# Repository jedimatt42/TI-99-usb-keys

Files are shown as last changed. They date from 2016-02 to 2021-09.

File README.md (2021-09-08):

# TI-99-usb-keys
Teensy 3.1 sketch to translate usb keyboard to TI-99/4a 15 pin interface.

This project interfaces a Teensy 3.1 and a Circuits@Home USB Host shield, to take input from a USB keyboard, and simulate the matrix keyboard built into the TI. 

The USB keyboard can be used with the TI keyboard still in place. The user can switch between them at will.

[Project Website](https://www.jedimatt42.com/ti99usbkeys.html)

## Design files

TIUSBKeys.rrb - PCBoard layout from Robot Room Copper Connection Studio Edition v3.0

gerber - folder containing necessary gerber images and drill files for printing pcboard

TIUSBKeys.sch - PCBExpress schematic source file

schematic.pdf - schematic exported to PDF

TI99USBKeys - folder containing arduino project files for Teensy 3.x

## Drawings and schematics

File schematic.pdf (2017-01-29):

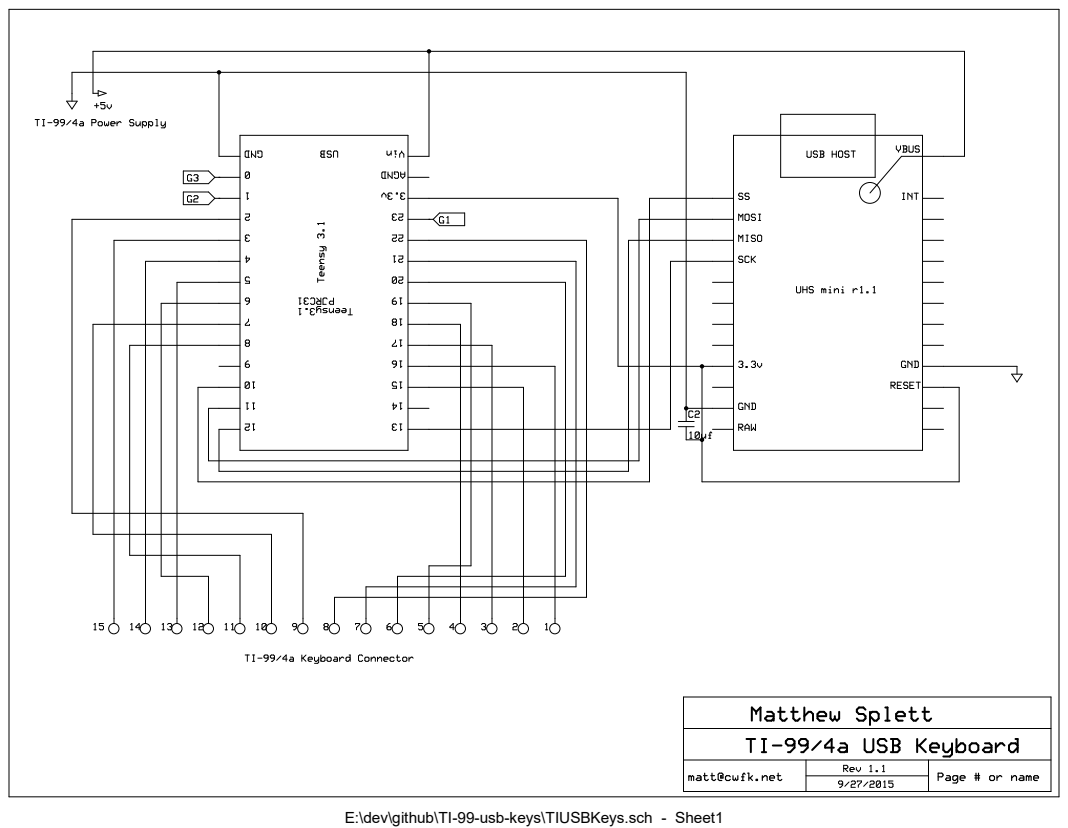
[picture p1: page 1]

E:\dev\github\TI-99-usb-keys\TIUSBKeys.sch - Sheet1

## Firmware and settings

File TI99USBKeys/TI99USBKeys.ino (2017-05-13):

#include <hidboot.h>
#include <usbhub.h>

// Satisfy the IDE, which needs to see the include statment in the ino too.
#ifdef dobogusinclude
#include <spi4teensy3.h>
#include <SPI.h>
#endif

// Reboot support
#define CPU_RESTART_ADDR (uint32_t *)0xE000ED0C
#define CPU_RESTART_VAL 0x5FA0004
#define CPU_RESTART (*CPU_RESTART_ADDR = CPU_RESTART_VAL);

#define NUMLOCK_STARTUP true
#define CAPSLOCK_STARTUP true
#define SCROLLLOCK_STARTUP false

#include "TiPins.h"

#include "TiVirtualState.h"

#include "TiScan.h"

#include "TiKbdRptParser.h"

USB     Usb;
USBHub     Hub(&Usb);
HIDBoot<HID_PROTOCOL_KEYBOARD>    HidKeyboard(&Usb);

TiKbdRptParser Prs;

long lastGoodState;
long firstBoot;

void setup()
{
  firstBoot = lastGoodState = millis();
  
  initData();

  // Wait for keyboard to be up
  while (Usb.Init() == -1)
    delay( 20 );

  HidKeyboard.SetReportParser(0, (HIDReportParser*)&Prs);
}

void gpioSetup()
{
  initPinModes();
  setColumnInterrupts();
}

void loop()
{
  // Read USB input which updates the state of the in-memory keyboard matrix.
  Usb.Task();

  long loopMillis = millis();
  uint8_t state = Usb.getUsbTaskState();
  
  if (state != USB_STATE_RUNNING) {
    if ((loopMillis - lastGoodState) > 5000) {
      CPU_RESTART;
    }
  } else {
    lastGoodState = loopMillis;
    if (firstBoot != 0) {
      // Set numlock and capslock on, leave scroll lock off.
      Prs.setKeyLocks(&HidKeyboard, NUMLOCK_STARTUP, CAPSLOCK_STARTUP, SCROLLLOCK_STARTUP);
      firstBoot = 0; 
      gpioSetup();
    }
  }
  if ((loopMillis - lastInterrupted) > 200) {
    onTiColumnChange();
  }
}

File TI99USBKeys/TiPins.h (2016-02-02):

#ifndef _TI_PINS_H
#define _TI_PINS_H

// teensy 3.1 pin aliases for TI keyboard connector. 
//   and info describing the meaning. 
//   _c? is a column input pin from the TI
//   _r? is a row output pin for the TI
int ti_c3 = 3; // key_cable_pin_15  (M J U 7 4 F R V)
int ti_c2 = 4; // key_cable_pin_14  (, K I 8 3 D E C)
int ti_c1 = 5; // key_cable_pin_13  (. L O 9 2 S W X)
int ti_c0 = 6; // key_cable_pin_12  (= space enter fctn shift ctrl)
int ti_r7 = 8; // key_cable_pin_11 (X C V B Z)
int ti_r6 = 7; // key_cable_pin_10 (ctrl W E R T Q)
int ti_c4 = 2; // key_cable_pin_9   (N H Y 6 5 G T B)
int ti_c5 = 22; // key_cable_pin_8   (/ ; P 0 1 A Q Z)
int ti_r4 = 21; // key_cable_pin_7  (fctn 2 3 4 5 1 alpha_lock)
int ti_c6 = 20; // key_cable_pin_6   (alpha_lock)
int ti_r0 = 19; // key_cable_pin_5  (= . , M N /)
int ti_r1 = 18; // key_cable_pin_4  (space L K J H ;)
int ti_r5 = 17; // key_cable_pin_3  (shift S D F G A)
int ti_r3 = 15; // key_cable_pin_2  (9 8 7 6 0)
int ti_r2 = 16; // key_cable_pin_1  (enter O I U Y P)

int ti_g3 = 0;
int ti_g2 = 1;
int ti_g1 = 23;

//-------------------------------------
// Initialize the TI interfacing pins.


void initInputs() 
{
  int inputMode = INPUT_PULLUP;
  pinMode(ti_c0, inputMode);
  pinMode(ti_c1, inputMode);
  pinMode(ti_c2, inputMode);
  pinMode(ti_c3, inputMode);
  pinMode(ti_c4, inputMode);
  pinMode(ti_c5, inputMode);
  pinMode(ti_c6, inputMode);
}

void initOutputs()
{
  // this mode seems to work well with letting the TI builtin keyboard still function.
  int outputMode = OUTPUT_OPENDRAIN; 
  pinMode(ti_r0, outputMode);
  pinMode(ti_r1, outputMode);
  pinMode(ti_r2, outputMode);
  pinMode(ti_r3, outputMode);
  pinMode(ti_r4, outputMode);
  pinMode(ti_r5, outputMode);
  pinMode(ti_r6, outputMode);
  pinMode(ti_r7, outputMode);
  digitalWrite(ti_r0,HIGH);
  digitalWrite(ti_r1,HIGH);
  digitalWrite(ti_r2,HIGH);
  digitalWrite(ti_r3,HIGH);
  digitalWrite(ti_r4,HIGH);
  digitalWrite(ti_r5,HIGH);
  digitalWrite(ti_r6,HIGH);
  digitalWrite(ti_r7,HIGH);

  pinMode(ti_g1, INPUT_PULLUP);
  pinMode(ti_g2, INPUT_PULLUP);
  pinMode(ti_g3, INPUT_PULLUP);
  digitalWrite(ti_g1,HIGH);
  digitalWrite(ti_g2,HIGH);
  digitalWrite(ti_g3,HIGH);
}

void initPinModes() 
{
  initInputs();
  initOutputs();
}

#endif

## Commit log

2015-09-10 Initial commit.
    Use mode to pins source for teensy to use opendrain mode of output pins
    for interfacing with pull up inputs on TI keyboard 'controller'
2015-09-13 remove the wait-for-serial loop so it will run off TI power supply.
    Also, added another sketch for experimenting with simply reading TI cru
    scans.
2015-09-13 Support strange directory requirements for Arduino IDE
2015-09-13 best guess at pinmodes for TI keyboard cable.
2015-09-16 basic buttons mapped, get lots of 'key-bounce' like behavior
    and some ghost keys from other columns. :(
2015-09-18 Fix mapping of single and double quote.
    Fix ti row updates to be faster. Seems fine. Now the key repeating has
    stopped.
    Added a naive version of alpha-lock. But it doesn't work well.
    I'm seeing some shift-lock like behavior that may be the result of the
    alpha-lock code.
    [TI99USBKeys.ino]
2015-09-20 first draft of schematic and pcboard.
    [TIUSBKeys.sch]
2015-09-20 capture some code that can soft reset the teensy. and document the keymap.
    [keymap.xlsx]
2015-09-20 Add ctrl-alt-delete to reboot adapter cpu. Fix F=.
    [TI99USBKeys.ino]
2015-09-20 Added data initialization explicit to setup.
    In case data segments are not otherwise initialized on reboot.
    [TI99USBKeys.ino]
2015-09-21 Forgot to undu an experiment. Put OPENDRAIN back.
    With my output pins in OPENDRAIN mode, they are either HIGH - not
    connected, or LOW - connected to ground. This doesn't interfere
    with the legacy keyboard at all... so they can both be present.
    [TI99USBKeys.ino]
2015-09-22 add scroll-lock and num-lock functions.
    Numlock is backwards for some reason. ( cause my code is bad.. and I
    haven't looked at it yet ) but the scroll lock works.
    I've also debugged the shift lock bug at the hardware level. And to my
    relief, it is a software problem :)
    [TI99USBKeys.ino]
2015-09-23 Hot plugging works.
    Waits on startup for device, and if device is disconnected / or any error,
    reboots after 5 seconds, which causes it to go back to waiting for device
    on startup.
    [TI99USBKeys.ino]
2015-09-26 This breakup now compiles and runs as before on the device.
2015-09-27 Finally fixed key lock states on start up.
    CapsLock and NumLock on by default.
    [TI99USBKeys.ino, TiKbdRptParser.h]
2015-09-29 A different layout approach.
    [TIUSBKeys.sch]
2015-09-30 Refine pcb layout, and adjust pin assignments to suite layout.
2015-10-03 Redo of pcboard layout to make it smaller.
    This will require updating the pin assignments.
    In a followup.
2015-10-04 even smaller so connectors protrude more.
2015-10-04 Update pin assignments to match board layout.
2015-10-04 Update pinouts on schematic.
    [TIUSBKeys.sch]
2015-10-09 Try using change interrupt detection.
    This should enable holding modifiers, and releasing keys more effectively.
    And if I'm lucky, it may get rid of the latency that causes '.', to produce
    strings of '.', and '/'...
2015-10-10 fix issues with repeating . and /, overlapping interrupts.
    Removed a few key specific hacks.
    So Fctn= is broken again. It won't release.
    [TI99USBKeys.ino, TiKbdRptParser.h]
2015-10-10 Fix alpha lock.
    It can coincide with other keys since it has a activation pin on the 9901,
    instead of the decoded set that go through the octal decoder.
2015-10-10 This fixes issues using the zero key in pinball II.
    I expected this to also replace my previous workaround for Fctn=, but it
    doesn't. It is like there is a bad interaction with the 9901 while it is
    resetting.
    [TI99USBKeys.ino]
2015-10-12 Fix fctn= to work with my normal failsafe relese mechanism.
    work arounds didn't help because they all made the assumption that the
    virtualstate was being cleared properly. It wasn't until I put the TI
    into a boot loop, that I realized the state must be stuck, and there it
    was, forcing on, instead of toggling like it should.
    [TI99USBKeys.ino, TiKbdRptParser.h]
2015-10-13 fix backspace to ignore scrolllock state, always be backspace.
    [TiKbdRptParser.h]
2015-12-13 update to include required 10uf cap over +3.3v input to USB Host mini.
    [TIUSBKeys.sch]
2015-12-14 Adjust lead spacing for larger capacitor.
2016-01-01 robot room copper connection format with gerbers.
    [TIUSBKeys.gbl, TIUSBKeys.gbs, TIUSBKeys.gko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]
2016-01-03 attempt to stop combo collisions
    stop things like holding down backspace and then pressing C from
    treeting it like a FCTN-C.
    [TiKbdRptParser.h]
2016-01-10 Bugs & Numpad with numlock off is all that is left.
    There is a bug noted in the onKeyUp. But otherwise all the
    coded mappings are working well.
    [TiKbdRptParser.h]
2016-01-10 Fix the release issue with weirdly mapped keys like doublequote.
    [TiKbdRptParser.h]
2016-01-24 Updated pcboard layout to rev2.
    Remove unnecessary/undesirable capacitor on +5v power for usb device.
    Remove mis-information from README.md
    Remove pcboard-express layout file, as my updates are being done in copper
    connection instead.
    [TIUSBKeys.sch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]
2016-01-29 Update to ground G1,G2,G3 when Ctrl-Alt-F10,F11,F12 are pressed.
    this enables wiring to TMS9900 for reset or load interrupt pin.
    [TiKbdRptParser.h, TiPins.h]
2016-01-31 Add polarity to capacitor on silk screen layer.
    [TIUSBKeys.gbl, TIUSBKeys.gbs, TIUSBKeys.gko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]
2016-02-02 Fix so when adapter reboots it doesn't trigger GPIO pins.
    [TiKbdRptParser.h, TiPins.h]
2016-03-16 Fix special keys that need to suppress shift and become a fctn.
    [TiKbdRptParser.h]
2016-03-19 Fix updating row outputs even if column inputs do not change.
    This allowed cleaning out some hacks that made F4 and F= work.
    [TI99USBKeys.ino, TiKbdRptParser.h]
2016-03-20 intercept keys after magic modifier translations.
    Fixes things like '] and backspace,e moving you up a line.
    [TiKbdRptParser.h]
2017-01-29 add schematic to aid those needing to debug
